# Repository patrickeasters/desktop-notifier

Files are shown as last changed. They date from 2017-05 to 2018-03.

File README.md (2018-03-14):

# distractify-button
Arduino sketch and accompanying shell script to send a desktop notification via
a physical button



## Why?
When working from my desk at work, I often wear my noise-cancelling headphones. They work really well, so if someone walks up to my desk, I often don't notice until they tap on my shoulder or start waving a hand near my face.

To provide a less intrusive means of getting my attention, I wanted to provide a method for a real life *push* notification (get it?).

## How it Works
The Arduino runs a simple sketch and is configured to be detected as a USB keyboard by my laptop. Once the sketch detects a button press, it sends an `F14` keypress to my work laptop running Fedora. GNOME is configured to map this event to execute a simple shell script that sends the desktop notification.

## Parts Needed
* Arduino Uno w/ [HoodLoader2](https://github.com/NicoHood/HoodLoader2) firmware
   - Note: custom firmware was needed to be able to utilize the USB port
* Momentary switch (I used a [30mm arcade button](https://www.aliexpress.com/item/Free-Shipping-Red-30mm-Arcade-Push-Button-Switch-Built-in-Micro-Switch-Perfect-Replace-SANWA-OBSF/32741696037.html))
* Custom 3D-printed button enclosure (optional I guess)

## Wiring it Up
There's not much to it, luckily! Since we're using the 16u2 chip rather than the IO chip, the switch is hooked up to pins on the ICSP header.

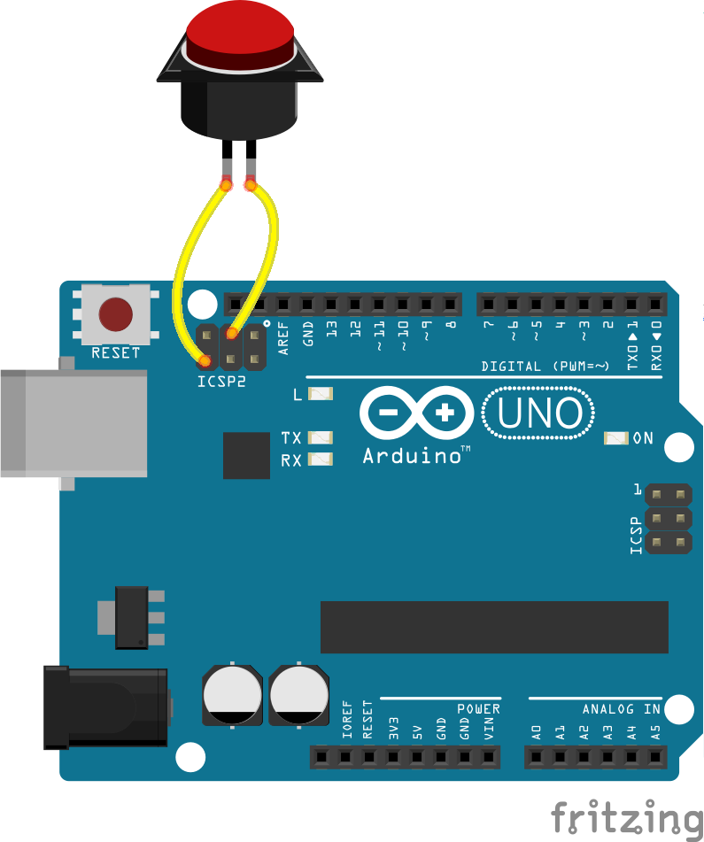
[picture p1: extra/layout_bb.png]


## What's Included
* Arduino sketch
* Shell script for notification
* OpenSCAD files for the button enclosure ([also on Thingiverse](https://www.thingiverse.com/thing:2348248))

## Comments/Questions?
Open an issue on Github or drop me an email/tweet! I'd love to see if you build your own.

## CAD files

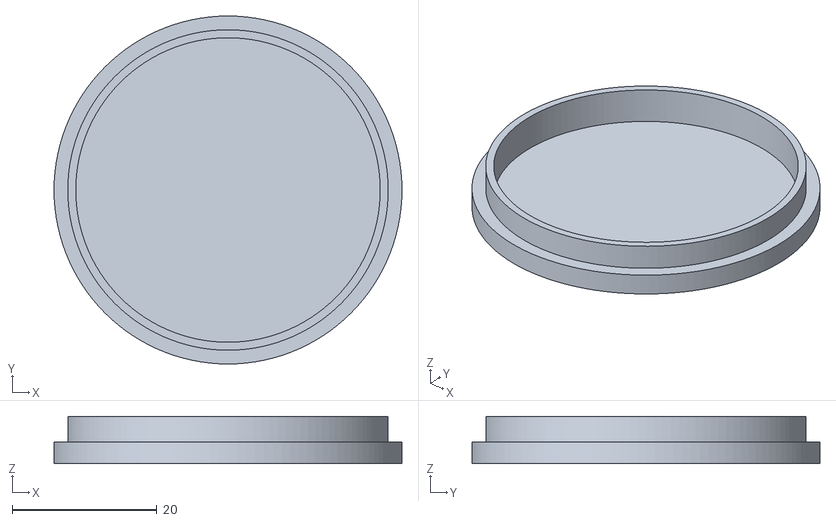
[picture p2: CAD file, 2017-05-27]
enclosure/base.stl
48.0 x 48.0 x 6.50

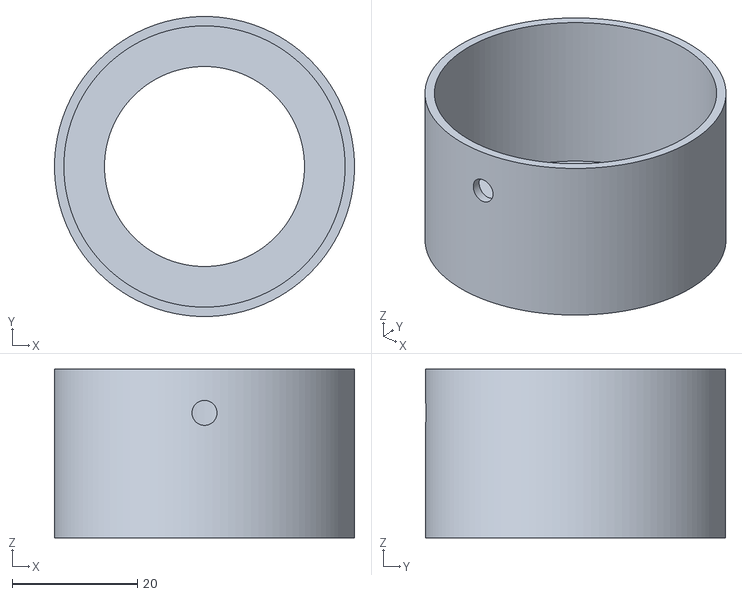
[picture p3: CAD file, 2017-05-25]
enclosure/lid.stl
48.0 x 48.0 x 27.0

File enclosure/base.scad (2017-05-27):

height=3;
diameter=48;
thickness=1.5;
resolution=120;

difference() {
    lid();
    translate([0,0,thickness]) cylinder(h=7, r=diameter/2-thickness*2, $fn=resolution);
}

module lid() {
cylinder(h=height, r=diameter/2, $fn=resolution);
translate([0,0,thickness]) cylinder(h=5, r=diameter/2-thickness-.4, $fn=resolution);
}

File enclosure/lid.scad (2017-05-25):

height=27;
diameter=48;
thickness=1.5;
resolution=120;

difference() {
    cylinder(h=height, r=diameter/2, $fn=resolution);
    translate([0,0,thickness]) cylinder(h=100, r=diameter/2-thickness, $fn=resolution);
    translate([0,0,-5]) cylinder(h=100, r=16, $fn=resolution);
    rotate ([90,0,0]) translate([0,20,0]) cylinder(h=100, r=2, $fn=resolution);
}

module tab() {
    
}

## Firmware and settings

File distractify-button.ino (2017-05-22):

#include "HID-Project.h"

const int pinButton = 1;

void setup() {
  pinMode(pinButton, INPUT_PULLUP);

  // The serial port is solely for debugging
  Serial.begin(115200);
  Serial.print("Running");

  // Initialize the keyboard
  Keyboard.begin();
}

void loop() {
  // Check if the pin is low (pulled down)
  if (!digitalRead(pinButton)) {

    // This key is otherwise unused in my OS
    Keyboard.write(KEY_F14);

    // Debug via serial
    Serial.println("Button press");


    // Simple debounce to prevent 7000 notifications due to the switch
    delay(300);

  }

}

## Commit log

2017-05-22 Adding initial versions of enclosure design
    [base.scad, lid.scad]
2017-05-22 Changing some sizes due to tolerances
    [base.scad, lid.scad]
2017-05-25 Giving up on the bayonet and just gluing this sucker
    [base.scad, base.stl, lid.scad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]
2017-05-27 Tweaking some tolerances
    [base.scad, base.stl]
2017-05-27 Updating the README and adding a quick Fritzing sketch
    [layout.fzz]
